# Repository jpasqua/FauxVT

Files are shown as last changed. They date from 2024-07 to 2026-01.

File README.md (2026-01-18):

# FauxVT

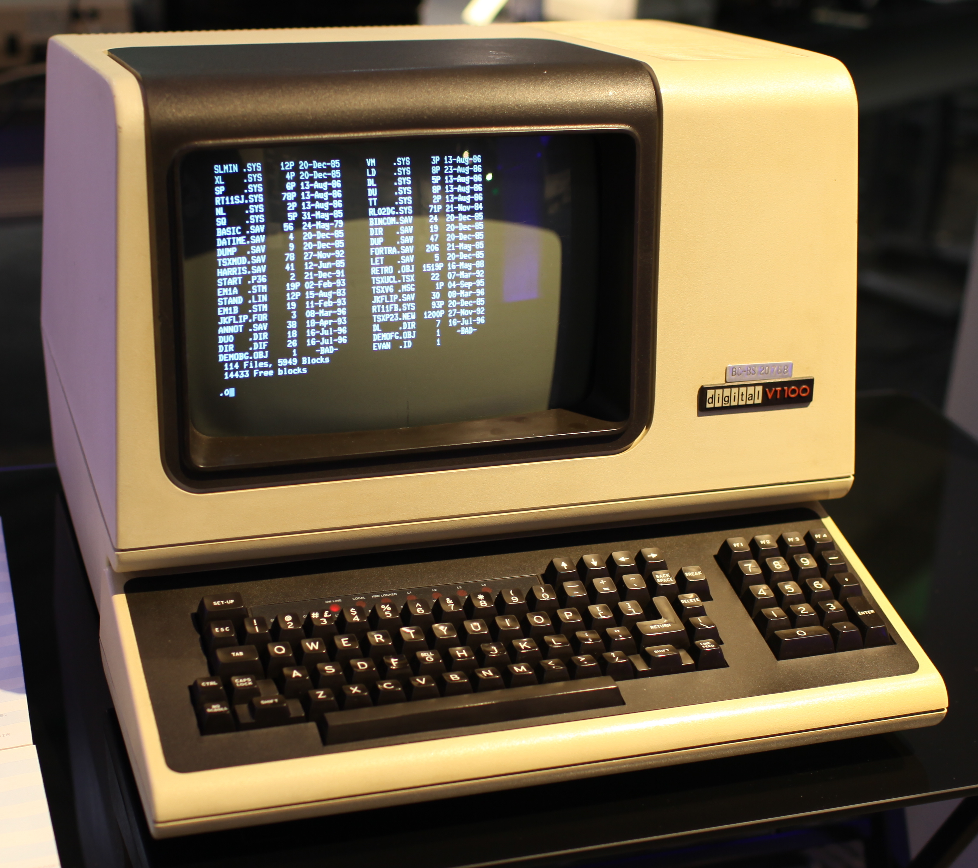
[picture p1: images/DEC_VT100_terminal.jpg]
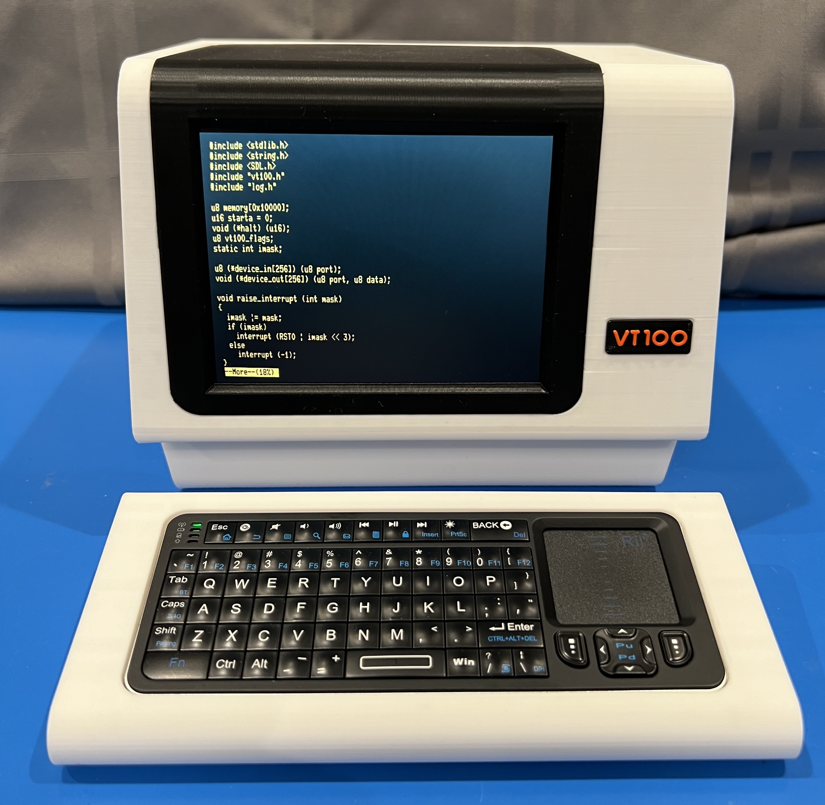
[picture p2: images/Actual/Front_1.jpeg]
[](images/Actual/Front_1.jpeg)

This repository contains the instructions for building a Faux VT100. The model is meant to evoke the feel of a [DEC VT100 terminal](https://www.vt100.net), but is not an exact replica. It has mounting spots for a Raspberry Pi, display, and associated hardware that allow you to run a terminal emulator and get the true VT100 experience.

There are two terminal emulators that make good choices for the FauxVT:

* The first is the wonderful [VT100 Simulator](https://github.com/larsbrinkhoff/terminal-simulator) by [Lars Brinkhoff](https://github.com/larsbrinkhoff). It is a faithful software simulation of the VT100 hardware including the original firmware ROM. Do you want to get in and use the setup menus like the old days? This is the way to go! Lars points at that the simulator is "somewhat experimental and the performance running on a Raspberry Pi could use some attention from an expert." 
* The second is the very aptly named [**C**ool-**R**etro-**T**erm](https://github.com/Swordfish90/cool-retro-term) by [Filippo Scognamiglio](https://github.com/Swordfish90). From GitHub: "cool-retro-term is a terminal emulator which mimics the look and feel of the old cathode tube screens. It has been designed to be eye-candy, customizable, and reasonably lightweight."

Take a look at a [short video](https://youtu.be/ITlj2mHSaQM) of the model in operation.

**[Instructions](Instructions.md)**: This document desribes how to print, assemble, wire, and prepare software for FauxVT.

***THIS IS A WORK IN PROGRESS***: The documentation on required electronics, wiring, and software setup is not complete. At this point you should consider yourself an alpha-tester!

The STL files for FauxVT can be found on [printables](https://www.printables.com/model/940494-faux-vt100-raspberry-pi-based-emulator-fits-inside).

## Other Models

If your vintage computer tastes run more towards classic Macs, check out the [Faux Mac](https://github.com/jpasqua/FauxMac). If you're a TRS-80 person, check out the [Faux TRS](https://github.com/jpasqua/FauxTRS).

## Potential Future Work

* **Audio**: Add an internal audio amp and speaker. Currently you can [set up an external bluetooth speaker or headphones](https://raspberrydiy.com/connect-raspberry-pi-bluetooth-speaker/) to get sound. In the future I may add an internal audio amp and speaker.
* **Configurable Back Plates**: Add an opening in the back of the case into which a connector platesmay be attached with screws. There could be many plates each of which offers a different configuration of external connectors. For example, one plate might have openings for 2 USB ports and 2 DB9 ports. Another plate might have USB ports and an opening for a micro-sd slot (extended from the Pi). This way the back of the case would be configurable without having many versions. A blank plate would be available for those who don't need any extra external ports.
* **Keyboard LEDs**: [Lars Brinkhoff](https://github.com/larsbrinkhoff/) recommends adding LEDs to the keyboard. 

## License: [][cc-by-nc]

This work is licensed under a
[Creative Commons Attribution-NonCommercial 4.0 International License][cc-by-nc].

[][cc-by-nc]

[cc-by-nc]: https://creativecommons.org/licenses/by-nc/4.0/
[cc-by-nc-image]: https://licensebuttons.net/l/by-nc/4.0/88x31.png
[cc-by-nc-shield]: https://img.shields.io/badge/License-CC%20BY--NC%204.0-lightgrey.svg

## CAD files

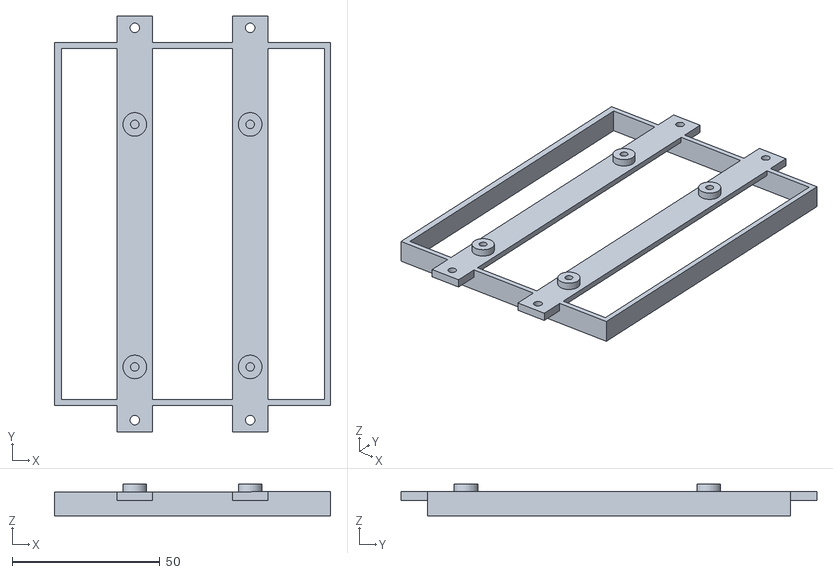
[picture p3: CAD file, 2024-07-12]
STLs/640x480/Display Retainer (NS).stl
93.4 x 140.7 x 10.8

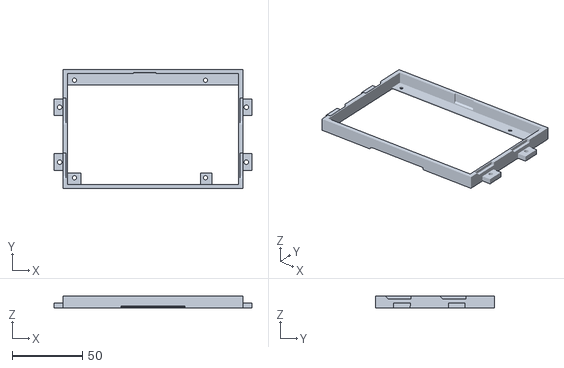
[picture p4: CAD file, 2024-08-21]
STLs/800x480/Display Retainer.stl
140.7 x 84.6 x 8.80

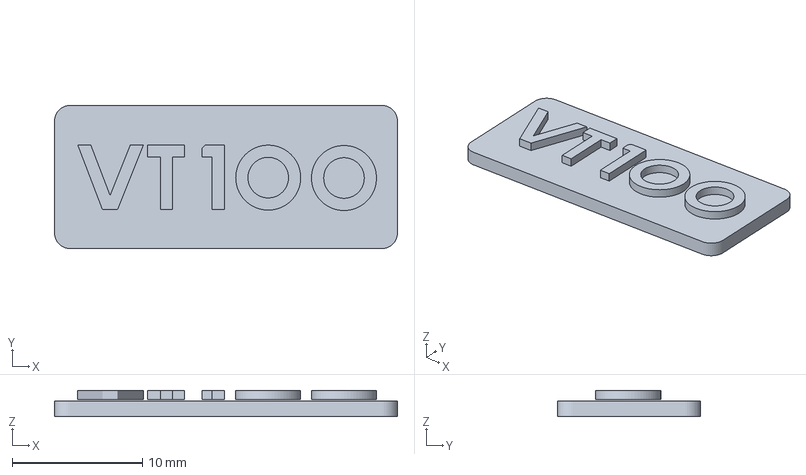
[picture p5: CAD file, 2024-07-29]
STLs/Badge.3mf
26.3 x 11.0 x 2.00 mm

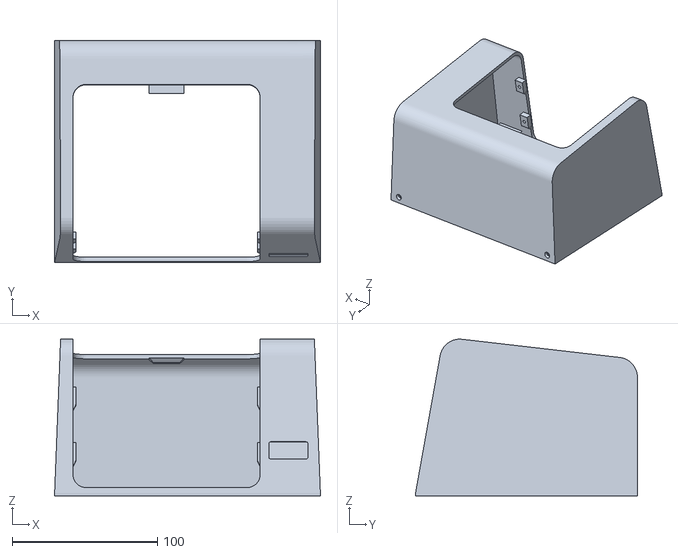
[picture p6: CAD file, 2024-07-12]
STLs/640x480/Top Case (NS).stl
183.0 x 152.7 x 107.9

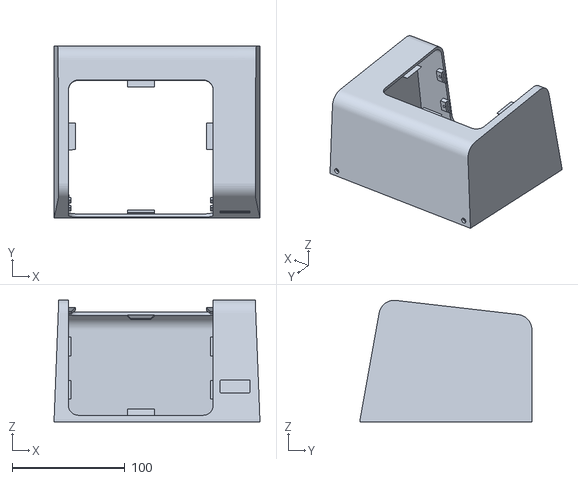
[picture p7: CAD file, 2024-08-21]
STLs/800x480/Top Case (NS).stl
183.0 x 152.7 x 107.9

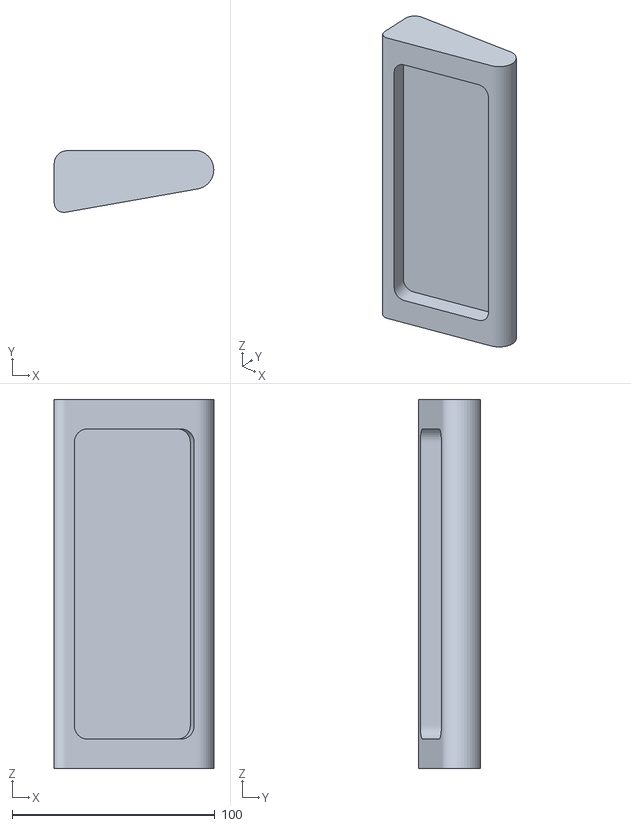
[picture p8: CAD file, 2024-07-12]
STLs/Keyboard Shell (NS).stl
78.7 x 30.5 x 182.0

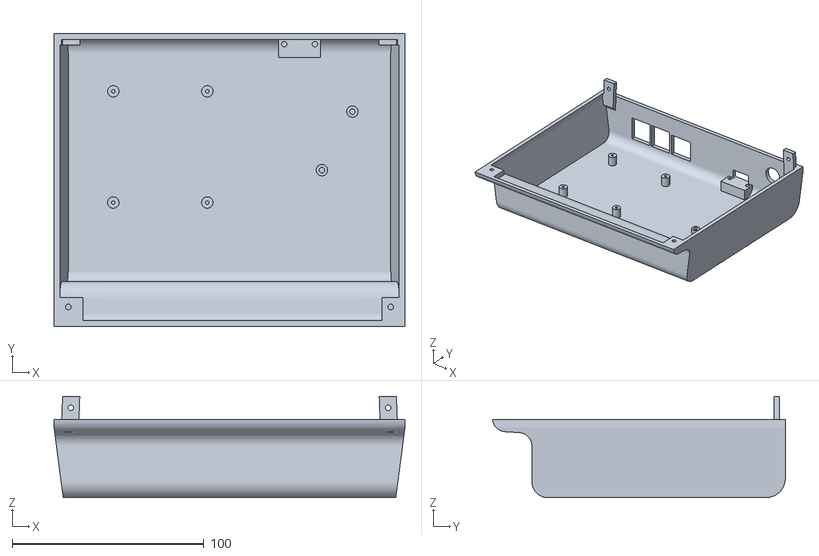
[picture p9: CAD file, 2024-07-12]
STLs/640x480/Bottom Case (NS).stl
183.0 x 152.7 x 52.9

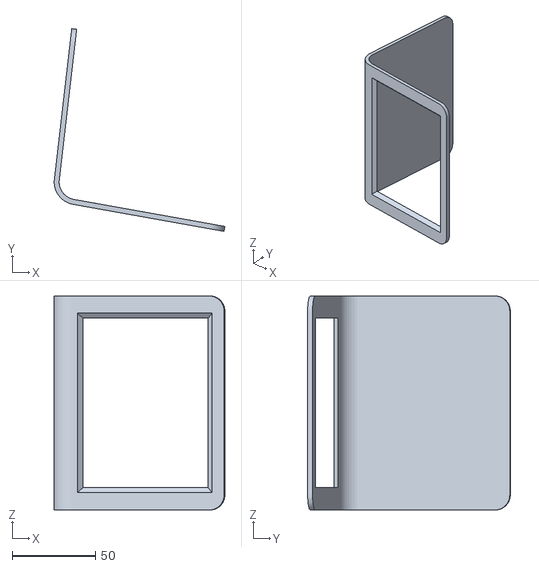
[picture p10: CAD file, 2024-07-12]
STLs/640x480/Insert (NS).stl
102.7 x 121.9 x 128.7

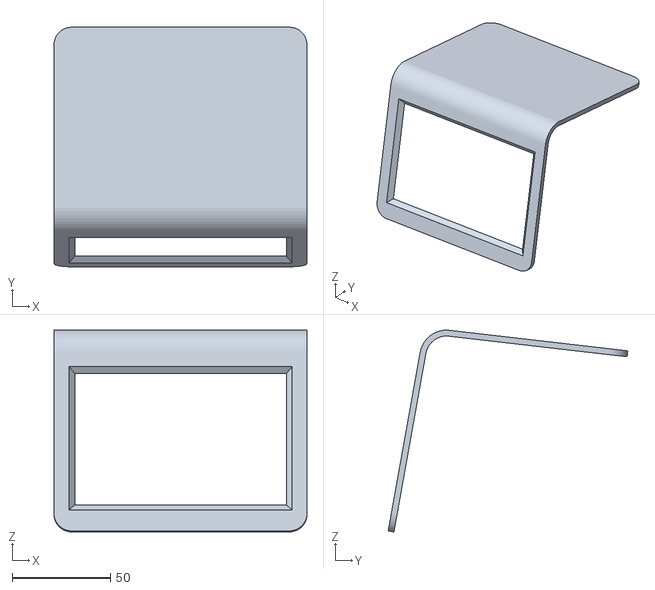
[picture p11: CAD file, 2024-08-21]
STLs/800x480/Insert (NS).stl
128.7 x 121.9 x 102.7

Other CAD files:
STLs/800x480/Bottom Case (NS).stl

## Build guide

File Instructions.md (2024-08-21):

# Building the FauxVT
These instructions are a work-in-progress. As problems are noted or suggestions arise, I will update the instructions as I have time. Thank you for your patience.

There are two variations of this model that are built around different displays: 800x480 and 640x480. The former has touch capability and makes assembly simpler since the Raspberry Pi mounts to it directly and it does not require a separate voltage. The latter (640x480) has an aspect ratio that is closer to the original and seems to have better off-axis viewing.

The instructions will point out where there are differences between the two versions. Throughout the Instructions when I am referring to a printed part, I will italicize the name. For example: *Top Case*. However, for most parts there are two versions which are kept in separate folders. Choose the one that is consistent with your display.

Below are some reference images of the assembled 640x480 model (click for full size images).

[](images/Actual/Front_1.jpeg)
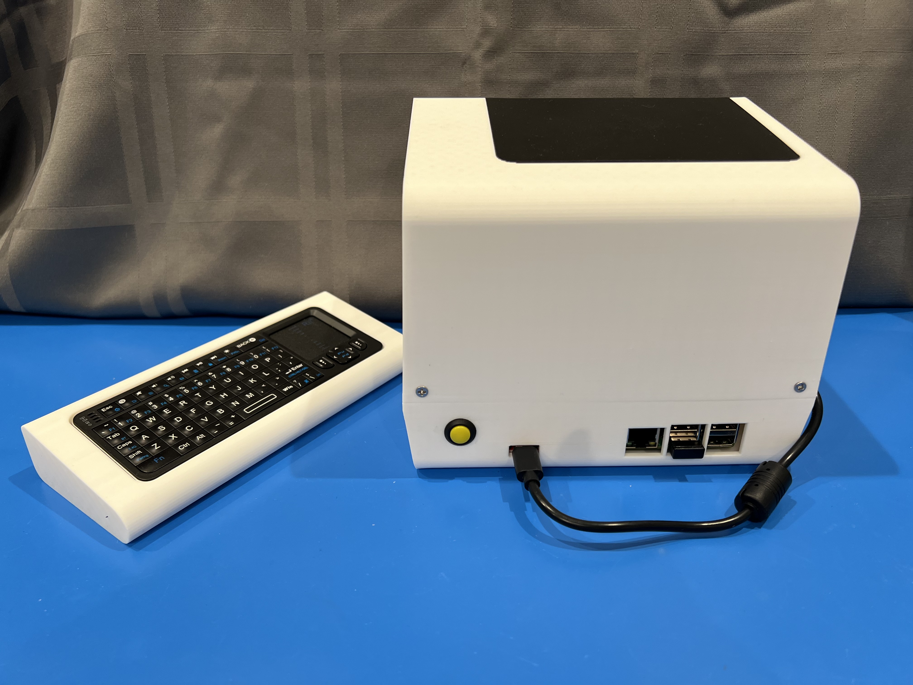
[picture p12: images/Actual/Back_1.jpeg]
[](images/Actual/Back_1.jpeg)
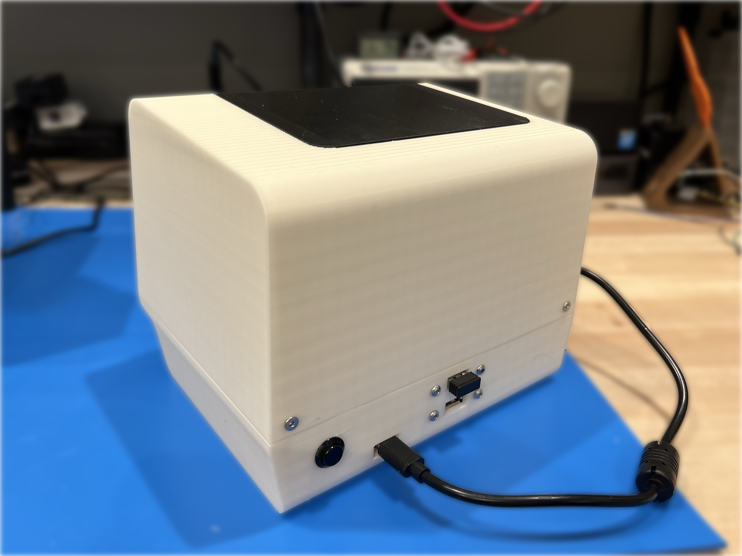
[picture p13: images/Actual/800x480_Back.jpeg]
[](images/Actual/800x480_Back.jpeg)

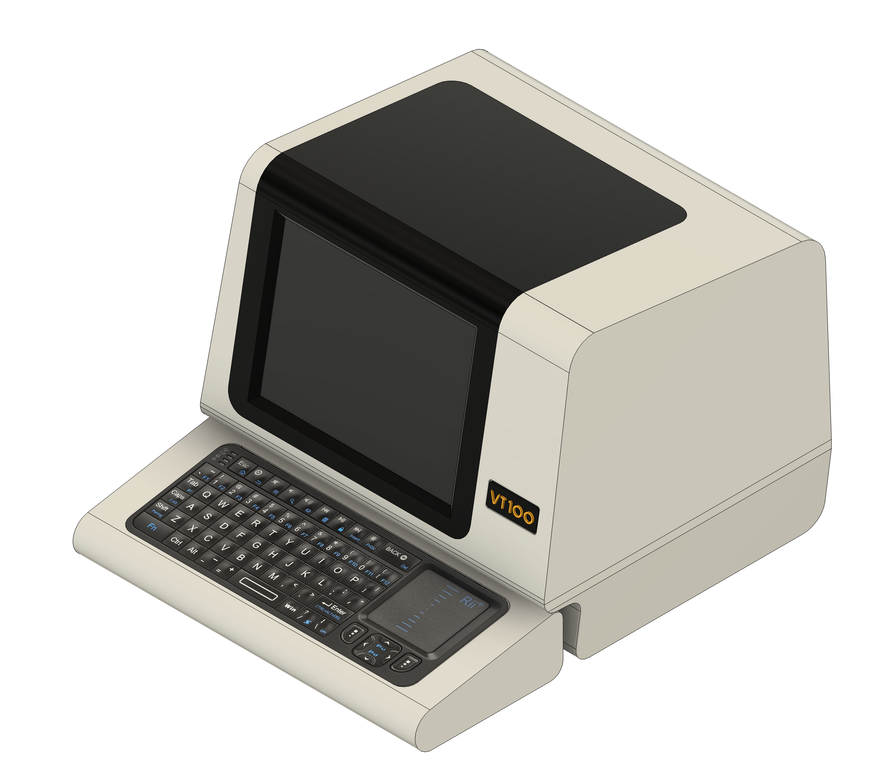
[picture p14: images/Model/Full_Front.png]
[](images/Model/Full_Front.png)
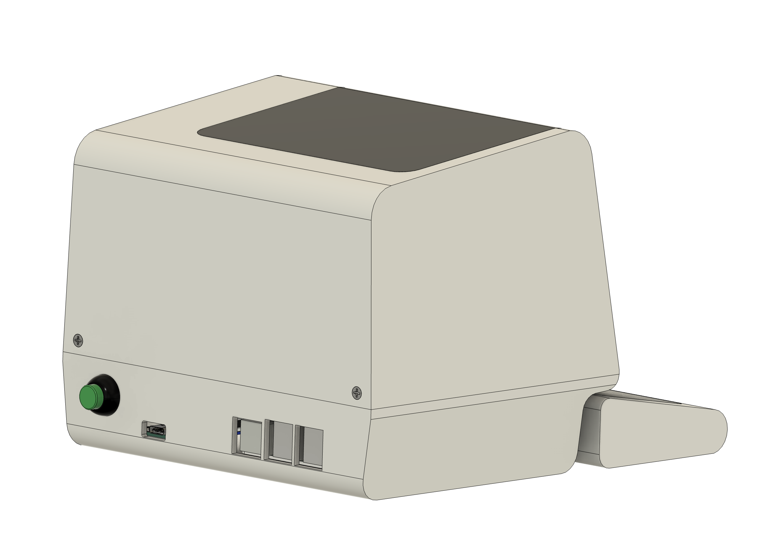
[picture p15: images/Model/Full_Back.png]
[](images/Model/Full_Back.png)

## Required Supplies

### Required Electronics

* **Raspberry Pi 3/4/5**. I use a model 3 and find the performance adequate. There are many places to source these. To find one you can use [rpilocator](https://rpilocator.com/).
* **Power Supply**. You will need a power supply with a USB-C connector that can support the Raspberry Pi and the display. The Pi is fairly power hungry so don't skimp here. If you do, you are likely to get "Low Voltage" warnings from the Pi. The [CanaKit Pi 4 Power Supply](https://www.amazon.com/gp/product/B07TYQRXTK) has worked for me, though I'm sure there are many others that will also work. What won't work is an old phone charger with a random USB cable.
* **Display** [OPTION]:
  * **5" 640x480 Display**. I used a 4x3 display to get the shape closer to the original aspect ratio, though still not quite as square. These are more difficult to find, but they are [available on eBay](https://www.ebay.com/itm/126148049546) along with the controller board which has an HDMI interface.
  * **5" 800x480 Display**.  This display ([available on Amazon](https://www.amazon.com/dp/B0BJJN9FZN)), provides touch capability and simpler assemble.
* **Keyboard**. The actual VT100 has a detachable keyboard as does FauxVT. In the model, the keyboard unit has a slot for a small wireless keyboard. The model I used will operate using Bluetooth or an included RF dongle. The model I used can be found on [AliExpress](https://www.aliexpress.us/item/3256805302970479.html).
* **USB-C breakout board**. This board fits in the *Bottom Case* and is the power jack for the model. You can find the board I used on [Amazon](https://www.amazon.com/dp/B09BW3HG49).
* **Power switch**. You need a standard latching push button. The one I used can be found on [Amazon](https://www.amazon.com/Cylewet-Self-Locking-Latching-Button-CYT1091/dp/B075VBV4QH).
* **Wires**
	* **USB Cable End**: I powered my Pi by plugging a USB cable into it as usual. I just used the end of a Micro-USB cable (since I used a Pi 3) and connected that to the incoming power through the switch.
		* **Important**: Be sure to use a good cable. Even at this short length, a cable with very thin wires will cause a voltage drop which will be reported by the Pi.
		* Note for 800x480 display: You may need a right-angle connector to ensure the cable doesn't bump into the *Bottom Case*. Check the fit of your cable before wiring it in.
	* **Bits of wire**. You'll need a few bits of wire to connect the breakout board, through the switch, to the Pi (via USB cable mentioned above) and the Boost converter. You'll also need wire to connect the output of the boost converter to the display.
* **Parts that are specific to the 640x480 Model**
	* **HDMI Cable**. The display connects to the Raspberry Pi via HDMI, but there is not any space for the typical bulky HDMI cables. I used a flat-flex cable with an up-angle HDMI connector for the display. The other end of the cable will depend on which Pi you use. I used a Flat-flex cable similar to [this one](https://www.amazon.com/JSER-HDMI-Type-Male-Cable/dp/B071FJY2BB), but with a micro-hdmi connector on one end. You can mix and match ends or buy a cable with both ends supplied (check the supplier's Amazon store). Be very careful to get the right one for your setup.
	* **Boost Converter**. The display runs on 12V, so you'll need to boost the 5V supply coming in. There are lots of available boost converters. The *Bottom Case* has mounting spots for [this one](https://www.amazon.com/gp/product/B0833SQF8Z).
	* **Barrel Jack**. You may wish to use a barrel jack to connect the boost converter to the display. I decided to solder wires to the display board rather than use a jack, but that is up to you.
	* **More Bits of wire**. You'll need wires in and out of the Boost converter.
* **Parts that are specific to the 800x480 Model**
	* Since the Raspberry Pi is attached directly to the back of the display, the USB ports are not accessible externally. Instead there are openings in the back of the model for panel-mount USB extensions such as [these from Amazon](https://www.amazon.com/gp/product/B07C87FYLY?ie=UTF8&th=1). I had to trim a little of the back of the USB connector to make the cable bend enough to fit. you might consider an angled connector for these.

### Required Hardware

You will need an assortment of screws to assemble the model:

* (2) M3x8 countersunk screws to attach the rear of the *Top Case* to the rear of the *Bottom Case*.
* (2) M3x8 cap head screws to attach the front of the *Bottom Case* to the front of the *Top Case*.
* (2) M3x4 cap head screws for the USB-C breakout board
* (4) M3x6 cap head screws to attach the *Display Retainer* to the *Top Case*
* **Hardware that is specific to the 640x480 Model**
	* (4) M3x4 cap head screws to attach the display board to the *Display Retainer*
	* (4) M2x4 cap head screws to attach the Raspberry Pi to the *Bottom Case*.
	* (2) M3x4 cap head screws for the Boost Converter
* **Hardware that is specific to the 800x480 Model**
	* (4) M3x6 cap head screws to attach the panel-mount usb connectors to the *Bottom Case*

Refer to the [reference images](#ScrewPlacement) in the Assembly section for placement.

### Filament

I used PLA for all components, but for no other reason than it is what I normally use and my models won't be in an environment where the properties of other filaments will be required. If this turns out to be untrue, I will update this note.

* **White Filament**: The *Top Case*, *Bottom Case*, and *Keyboard Shell* should be printed in White Filament to match the VT100. I am looking for suggestions on which specific filament matches the VT100 best. If you know of a matching paint, you could print the model in a neutral white and spray paint it. If you do this, you'll need to be careful about the tolerance of the fit between the Top Case and the Insert.
* **Black Filament**: This is used for the *Insert* and the base of the *Badge*. You can also use black, or any other color filament, for the internal parts such as the *Display Retainer*.
* **Orange Filament**: A very small amount of orange filament is need for the letters on the *Badge*.
* Thanks to [research](https://github.com/larsbrinkhoff/terminal-simulator/issues/31) by Lars Brinkhoff, we have better data on the actual colors of the VT100 so we ought to be able to find a closer filament match. Specifically, the *Top Case* and *Bottom Case* are closest to one of these Pantone colors: Pantone 2323 C, 7527 C, and 7534 C. The dark parts (e.g. *Insert* and *Badge* base) are close to Pantone 412 C.

### Other
* **CA Glue**: A small amout of CA glue is needed to attach the *Insert* to the *Top Case*.
* **Patience**: This can go a long way towards a successful build.

## Printing the Parts

Printing and assembling this model will take some time. The largest part, the main case, requires supports and takes me about 10.5 hours to print on a BambuLab X1. All of the STLs will import into your slicer in the orientation in which I printed them. STLs that need supports have “(NS)” in the name. I used tree support and removing them wasn't too bad. All parts may be printed with a 0.2mm layer height.

* ***Badge.3mf***: You may have noticed that while other model files are `.stl` files, the *Badge* is a `.3mf`. That's because this is a multi-color component and a `3mf` allows me to provide more details for people who have printers capable of handling multiple colors automatically. If your printer doesn't handle multiple colors automatically, don't worry. You can still use this file and do a manual filament change.
  * Standard printer: The base is 1.2 mm tall. You'll need to tell your slicer to set a pause after the base is printed. That will give you an opportunity to change from black filament to orange. The details of how to do that vary by slicer. I've provided [a screen shot](images/Assembly/BadgePausePrusa.jpeg) of how it is done in PrusaSlicer (very similar in Bambu Studio and Orca Slicer). Note that while the base is 1.2mm tall, you set the pause at 1.4mm since the pause occurs *before* the layer is printed.
  * Multi-color printer: The `3mf` file is split into separate parts for the base and the letters. Use your slicer to set the base color to black and the letter color to orange. [This screenshot](images/Assembly/BadgePartsBambu.jpeg) shows the settings in Bambu Studio. It's similar in other slicers.
* ***Bottom Case (NS).stl***. This component requires supports to hold up the front lip. Note that there are two screw holes in this lip which have built-in single layer (0.2mm) bridges. This avoids supports in a hard-to-cleanout area. Simply poke a small hex key through the bridged area after printing. 
* ***Display Retainer (NS)***. This part screws into the main case and the Front Insert to hold the display in place. Note that that the 800x480 variant of this part does not require supports, so it doesn't have "(NS)" in the name.
* ***Insert (NS).stl***. This component fits into the opening of the *Top Case* and provides the bezel for the screen. It requires supports along the top edge of the bezel.
* ***Keyboard Shell (NS).stl***. This standalone component houses the small wireless keyboard. It is listed as requiring supports, though technically it doesn't if printed in it's natural orientation. I print it on end to avoid stair-step ridges in the top of the shell. You can re-orient it to avoid supports if you prefer.
* ***Top Case (NS).stl***. This is the largest single print and, as the name shows, requires supports. Though this part can be printed at a 0.2mm layer height, the top has a gentle slope which may create visible ridges. You may choose to print this section of the model with a smaller layer height to mask the stair-step effect.

## Assembly

After printing the parts, removing supports, and doing any other cleanup/post-processing you see fit, you are ready to assemble the model. The steps below are for the physical assembly, but you'll need to do the wiring along the way. An overview of the wiring is given in a separate section, but is called out in step 8 below.

1. All of the screws mount directly into the plastic of the model. You may want to run some screws into the holes a bit to make it easier to start the screws during the actual assembly process. Don't over-tighten.
1. Position the *Insert* into the opening in the *Top Case*. There are some tabs in the *Top Case* to help with the positioning of the *Insert*. Adjust the fit so that there is little to no space between the parts. When you're happy that it fits well, remove it and put a small amount of CA glue on the support tabs. From the inside of the case, use more CA glue on the seam between the *Top Case* and the *Insert*. See the reference images below.
2. Using a small amount of CA glue, affix the Badge into the recessed area on the *Case* to the right of the display opening.
3. *640x480 Version*:
	1. Very carefully thread the flat-flex cable from the display through the *Display Retainer* and connect it to the connector on the display board. It is very easy to rip this cable and extremely hard to fix it. See the photos for proper orientation.
		* **NOTE**: At this point you should have soldered wires to the back of the display board if you are not going to use the barrel connector (see wiring notes below).
	1. Screw the display board to the back of the retainer. Use at least 2 screws, but preferably all 4.
	* **NOTE**: The display board comes with a control board with several buttons. The boards are connected to one another through a fairly flat 6-wire cable. You won't be using the control board in normal operation, but it is useful to have it connected during initial setup to adjust things like input source, brightness, etc. It is tough to connect the cable once the display is installed. You may wish to plug in the cable before installing the display assembly. You don't need to leave the control board connected after initial setup, but you can leave the cable installed.
2. *800x480 Version*: Attach the Raspberry Pi to the back of the display. Ensure the GPIO header is aligned properly and insert the U-shaped HDMI connector. Refer to the instructions that are provided with the display. Install the USB extension cables before attaching the Pi. Unless you are using low profile, angled USB cables, you won't be able to plug these in once the Pi is in place.
1. Install the display assembly including the display itself and the *Display Retainer* into the case. Install four screws through the *Display Retainer* into the tabs at the front of the *Top Case*. Remember to peel off the clear protective plastic from the front of the display before you screw it in place!
1. *640x480 Version*: Install the Raspberry Pi using four M2 screws.
1. Install the power switch
1. ***Perform wiring as described below***
1. Secure the USB C breakout board using two M3 screws
1. *640x480 Version*: Secure the Boost Converter using two M3 screws
1. After testing the unit, secure the *Top Case* to the *Bottom Case* using two screws at the front and two are the back.
2. I put a small self-adhering rubber foot at each corner of the bottom of the *Bottom Case* to make it less likely to slide. This is completely optional. I used some feet I happened to have lying around, so I'm not sure exactly what they are. They look like [these](https://www.amazon.com/Adhesive-Drawers-Furniture-Dampening-Transparent/dp/B08NX9KXQP).

2. Have a break then move on to Software Setup.

**Reference Images**:

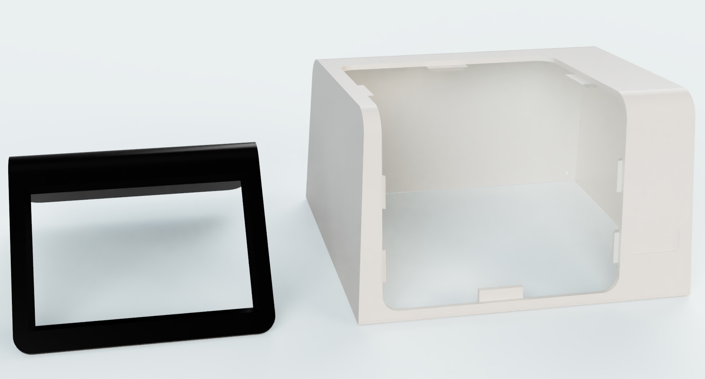
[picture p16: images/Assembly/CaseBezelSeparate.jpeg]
[](images/Assembly/CaseBezelSeparate.jpeg)
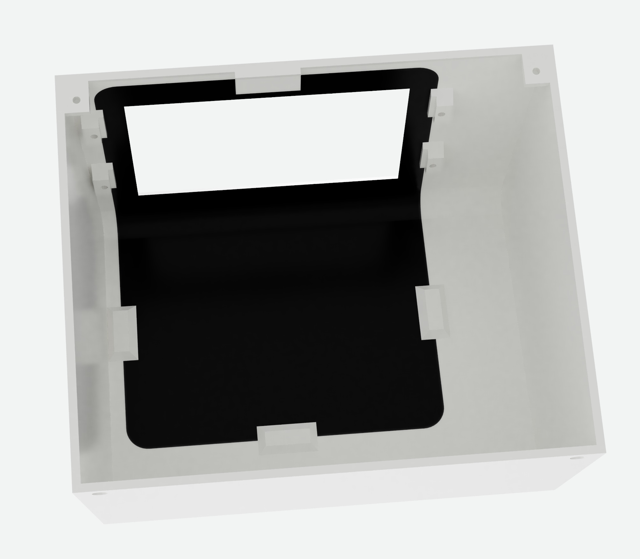
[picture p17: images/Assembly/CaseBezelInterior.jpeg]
[](images/Assembly/CaseBezelInterior.jpeg)
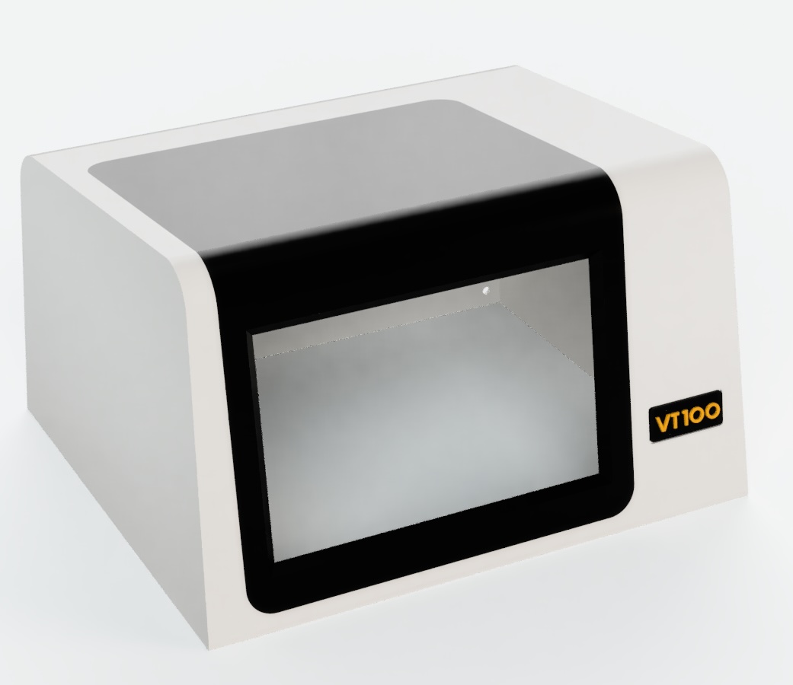
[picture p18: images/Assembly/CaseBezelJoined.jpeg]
[](images/Assembly/CaseBezelJoined.jpeg)
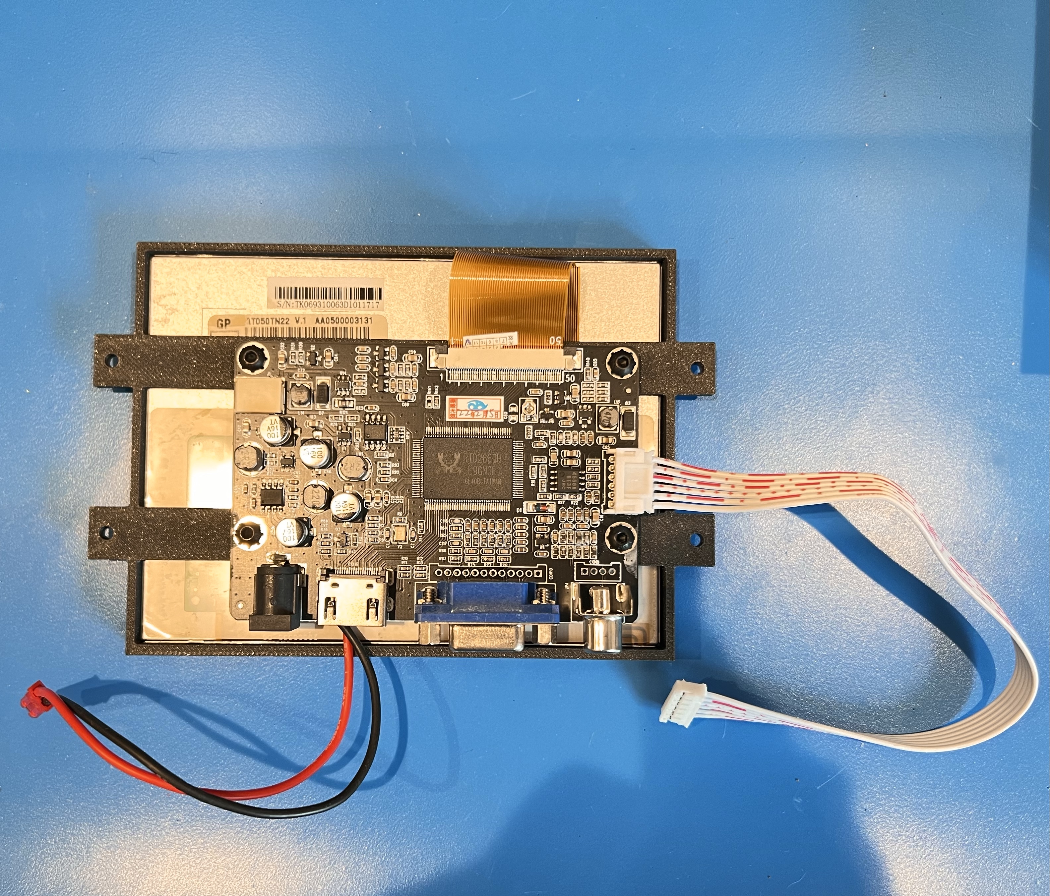
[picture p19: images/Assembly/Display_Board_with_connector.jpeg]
[](images/Assembly/Display_Board_with_connector.jpeg)

Screw Placement (Both Variants):

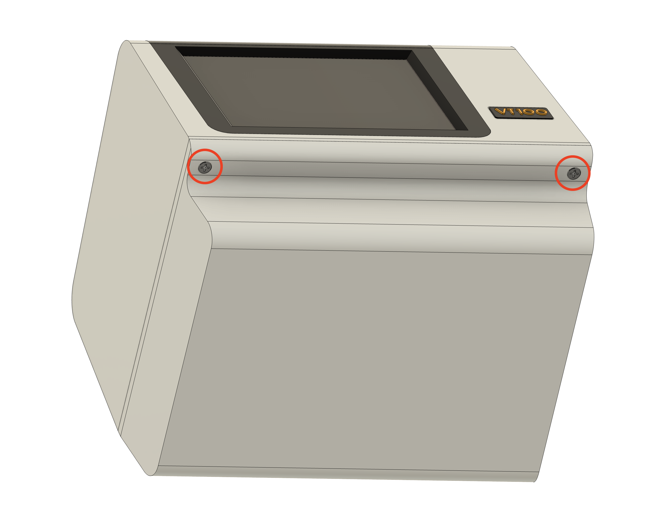
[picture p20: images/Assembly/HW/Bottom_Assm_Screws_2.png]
[](images/Assembly/HW/Bottom_Assm_Screws_2.png)
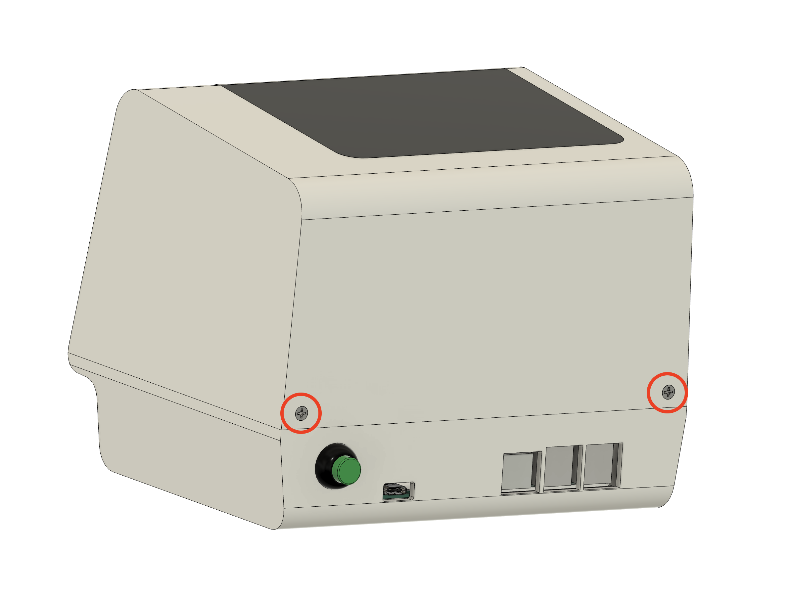
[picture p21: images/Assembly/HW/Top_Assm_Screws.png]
[](images/Assembly/HW/Top_Assm_Screws.png)

Screw Placement (640x480):

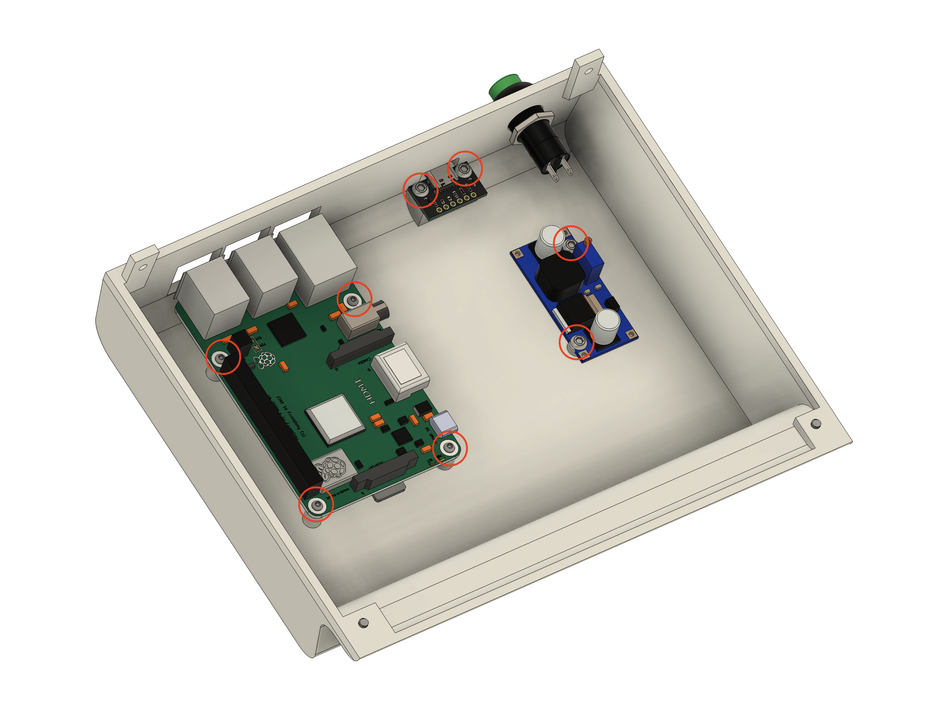
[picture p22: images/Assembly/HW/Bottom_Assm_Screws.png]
[](images/Assembly/HW/Bottom_Assm_Screws.png)
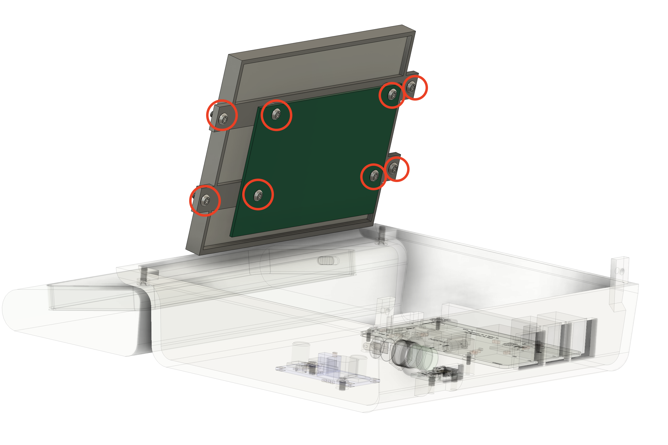
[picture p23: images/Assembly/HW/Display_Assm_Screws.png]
[](images/Assembly/HW/Display_Assm_Screws.png)

Screw Placement (800x480):

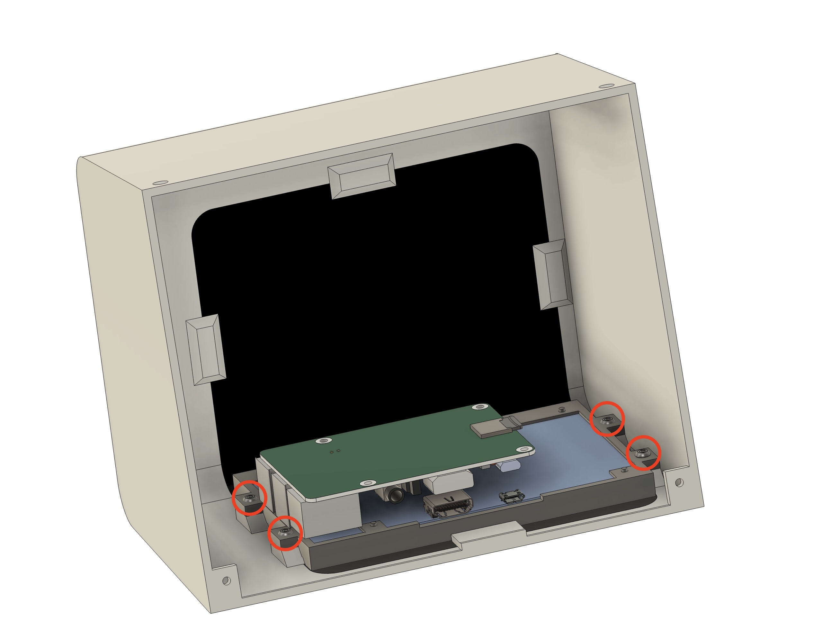
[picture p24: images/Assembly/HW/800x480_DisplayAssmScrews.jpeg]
[](images/Assembly/HW/800x480_DisplayAssmScrews.jpeg)
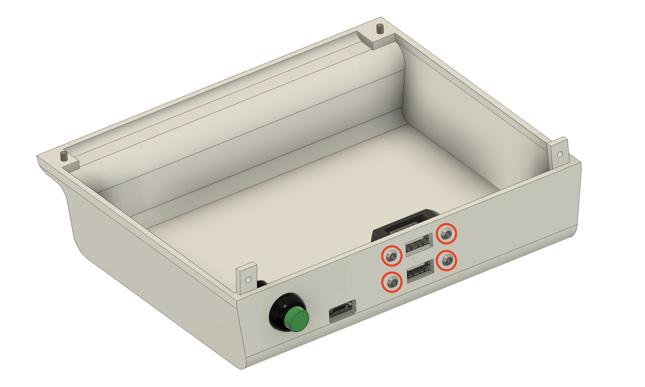
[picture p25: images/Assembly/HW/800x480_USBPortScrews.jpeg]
[](images/Assembly/HW/800x480_USBPortScrews.jpeg)

## Wiring

The wiring is very simple for the 800x480 version and fairly simple for the 640x480 version. You can see most of it in the photos. I will trace through the connections starting with the USB-C connector. Depending on how much you want to facilitate disassembly and changes, you may wish to use two prong connectors at certain spots. Refer to the images to see where I used connectors.

1. Connect `VBUS` on the USB breakout board to one leg of the power switch.
1. Connect the other leg of the power switch to the positive (red) leg of the USB Cable End.
1. Connect `GND` on the USB breakout board to to the ground (usually black or white) leg of the USB Cable End.
1. *640x480 Version*:
	2. Also connect the ouput of the power switch to `IN+` on the Boost converter. 
	3. Also Connect `GND` on the USB breakout board to `IN-` on the Boost converter. 
	2. Output from the Boost Converter. You have a couple of options here:
		2. Connect the outputs of the boost converter (`OUT+` and `OUT-`) to a cable with a male barrel connector on the end. It should correspond to the female barrel connector on the display. Plug in the barrel connector.
		3. *Alternatively*, solder a red wire and a black wire to the back of the display board. If you look at the board near the barrel jack you'll see pads labeled `12V` and `GND`. You can use those or solder directly to the  legs of the barrel connector. If you use this method, it is convent to put some type of 2-pin connector between the Boost converter and display so they can be separated easily. This is the approach I took. See the reference photo.
    4. **Important**: Adjust the Boost Converter output to 12V. If the voltage is too high, it may damage your controller board.
	1. Connect the angled HDMI connector to the input of the display board.
	1. Connect the free end of the HDMI cable to the Raspberry Pi.
1. Plug the USB Cable End into the Raspberry Pi.

**Reference images (640x480)**:

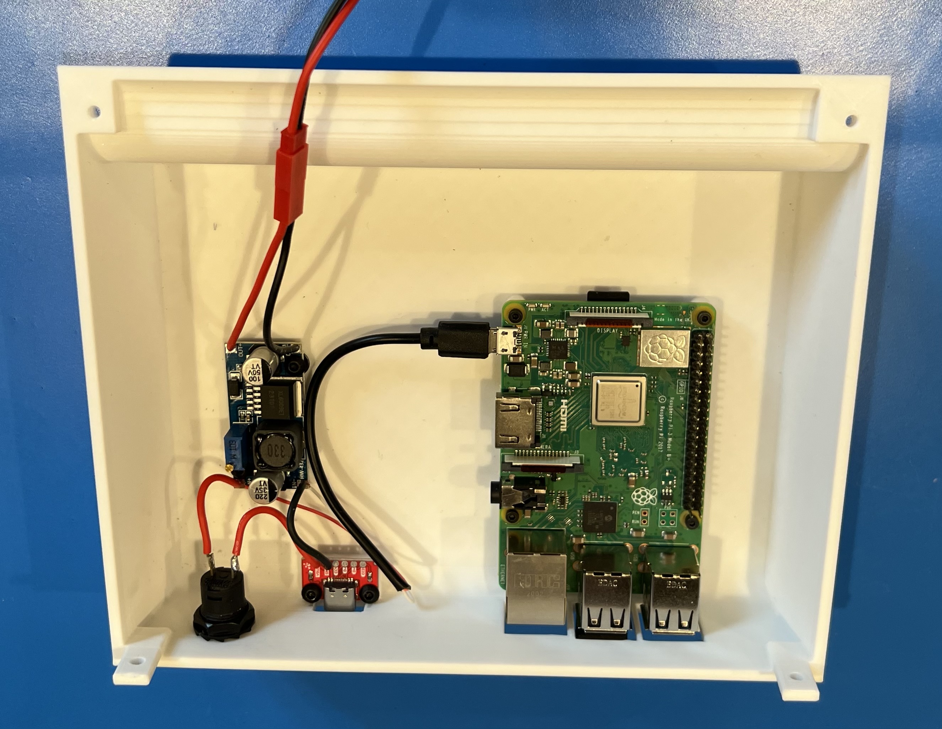
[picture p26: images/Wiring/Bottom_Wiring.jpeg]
[](images/Wiring/Bottom_Wiring.jpeg)
[](images/Assembly/Display_Board_with_Connector.jpeg)
[](images/Wiring/Display_Board_Power.png)

**Reference images (800x480)**:

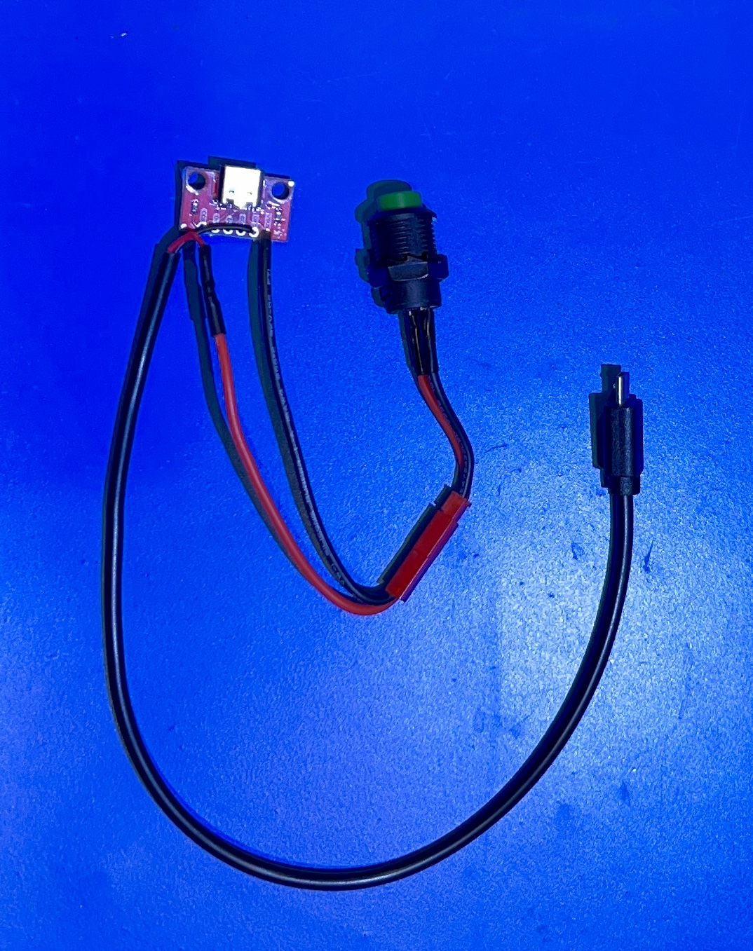
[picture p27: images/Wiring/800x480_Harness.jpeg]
[](images/Wiring/800x480_Harness.jpeg)
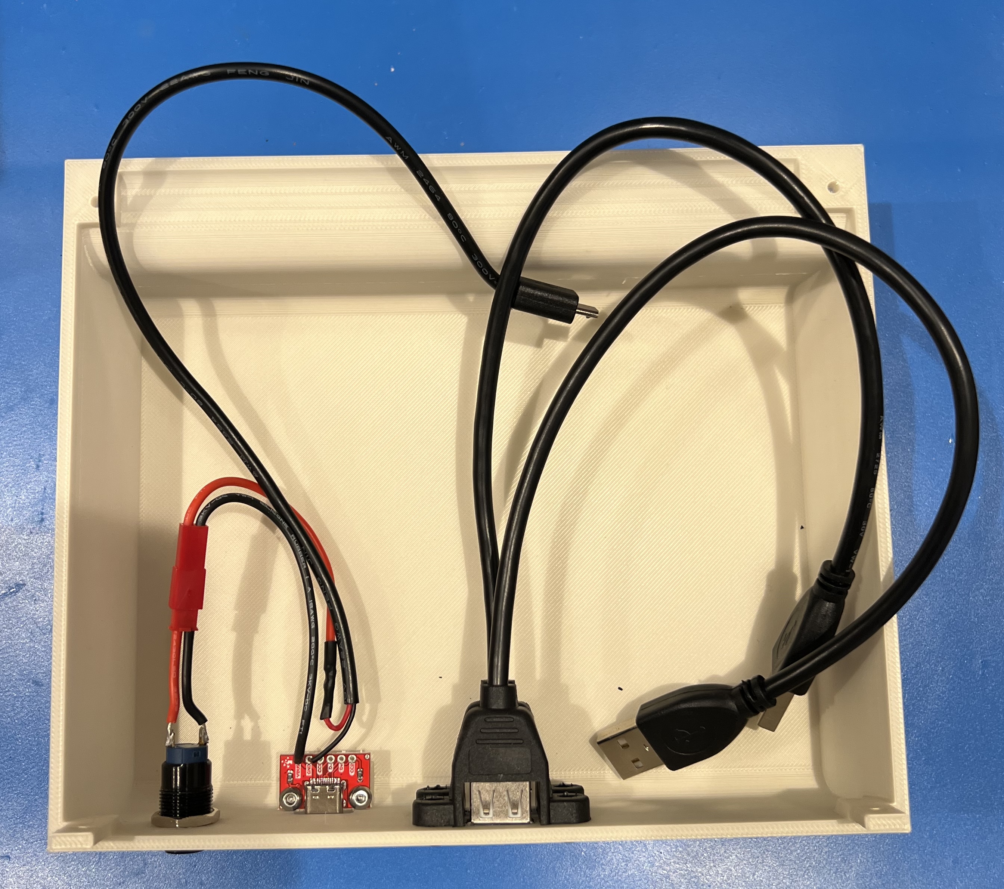
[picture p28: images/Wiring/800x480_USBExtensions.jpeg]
[](images/Wiring/800x480_USBExtensions.jpeg)

## Software Setup

* **Prepare Raspberry Pi OS**. Create an image of the Raspberry Pi OS that is appropriate for your Pi. Don't use the Lite version - you'll need the window system installed.
* **Flip the display**. Because of the placement of ports on the display, it must be mounted upside down in the case. This means that the displayed images need to be inverted. This is accomplished using the Screen Preferences in the Raspberry Pi desktop. Selected the inverted option.

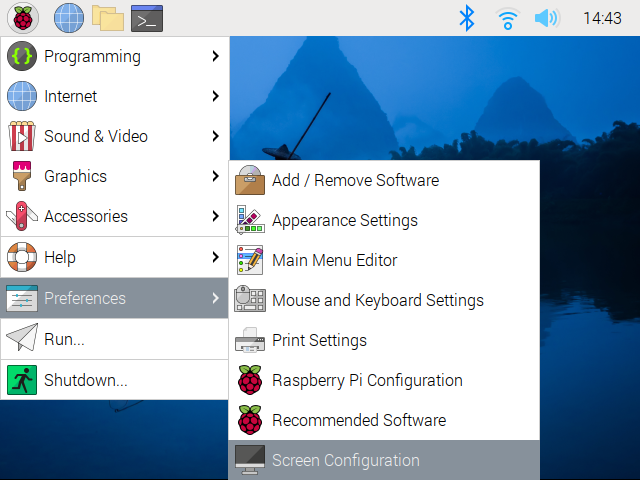
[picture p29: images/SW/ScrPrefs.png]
	[](images/SW/ScrPrefs.png)
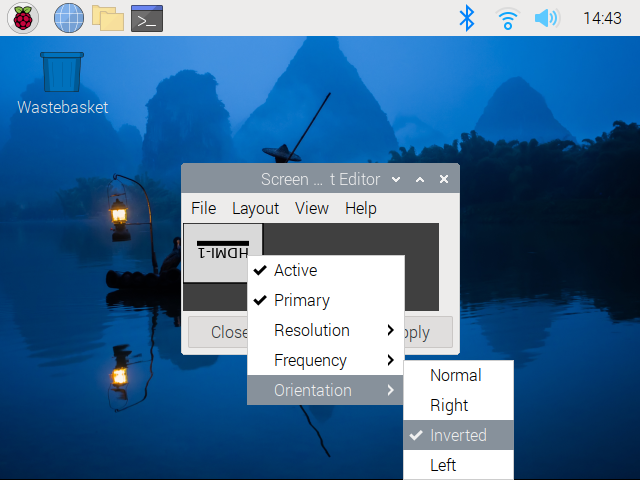
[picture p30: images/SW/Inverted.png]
	[](images/SW/Inverted.png)

  Once you've done this, the Window System will display properly. Note, however, that as the Pi is booting, everything will appear upside down until the window system launches.
* **Install a Terminal emulator**. These are the two terminal emulators I recommend:
    * The first is the wonderful [VT100 Simulator](https://github.com/larsbrinkhoff/terminal-simulator) by [Lars Brinkhoff](https://github.com/larsbrinkhoff). It is a faithful software simulation of the VT100 hardware including the original firmware ROM. Do you want to get in and use the setup menus like the old days? This is the way to go! Lars points at that the simulator is "somewhat experimental and the performance running on a Raspberry Pi could use some attention from an expert."
    * The second is the very aptly named [**C**ool-**R**etro-**T**erm](https://github.com/Swordfish90/cool-retro-term) by [Filippo Scognamiglio](https://github.com/Swordfish90). From GitHub: "cool-retro-term is a terminal emulator which mimics the look and feel of the old cathode tube screens. It has been designed to be eye-candy, customizable, and reasonably lightweight."
* Optional: Create desktop icons for your terminal emulators, or choose one and automatically launch it full screen when the window system launches.

## Notes you don't care about

* The `3mf` for the *Badge* was prepared in PrusaSlicer, while all the other `stl` files were prepared in Bambu Studio. Unfortunately, if I create the `3mf` in Bambu Studio it is not processed properly by PrusaSlicer (last test 2024-07-29)

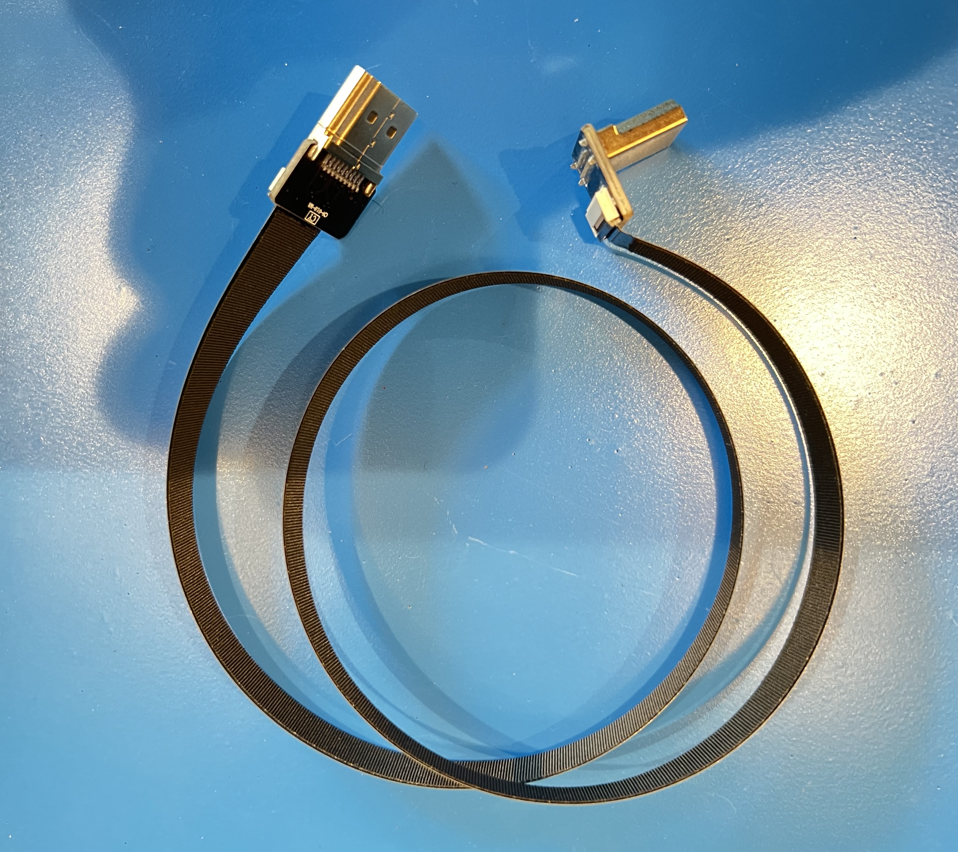
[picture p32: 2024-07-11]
images/Assembly/HDMI_Cable.jpeg

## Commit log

2024-07-12 Finish up v1
    [Badge.stl, Bottom Case (NS).stl, Display Retainer (NS).stl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]
2024-07-12 Fix printables link
2024-07-12 Update filament info
2024-07-15 Added note about filament type.
2024-07-18 Fix screw spec for front of case
2024-07-29 Update the Badge and assoc'd docs
    [Badge.3mf, Badge.stl]
2024-08-21 Added and organized STL files. Lots more doc work.
    [Bottom Case (NS).stl, Display Retainer (NS).stl, Display Retainer.stl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]
2024-08-21 Various updates (see details)
    * Move STL directory to top level
    * Add instructions for the Sound Box
    * Add Sound Box STLs
    [Badge.3mf, Bottom Case (NS).stl, Display Retainer (NS).stl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]
2024-08-21 Move STLs to top level. Fix typos
    [Badge.3mf, Bottom Case (NS).stl, Display Retainer (NS).stl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]
2024-08-21 Updated the 800x480 display retainer
    [Display Retainer.stl]
